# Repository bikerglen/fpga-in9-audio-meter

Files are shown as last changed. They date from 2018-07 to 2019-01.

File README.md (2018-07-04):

# fpga-in9-audio-meter
<p>Clone repo to convenient location</p>
<p>Launch Vivado 2018.2</p>
<p>In TCL console:</p>
<p>cd [path to create project]</p>
<p>source [path to repo]/vivado/create-project.tcl</p>
<p>generate bitstream</p>
<p>export hardware / local / do not include bitstream</p>
<p>launch sdk</p>
<p>create new xilinx standalone hello world application</p>
<p>replace helloworld C code with contents of sdk-c/helloworld.c</p>
<p>add 'm' to helloworld -> properties -> C/C++ Build -> Settings -> Libraries
</p>
<p>to do: rewrite cordic using generate loops</p>

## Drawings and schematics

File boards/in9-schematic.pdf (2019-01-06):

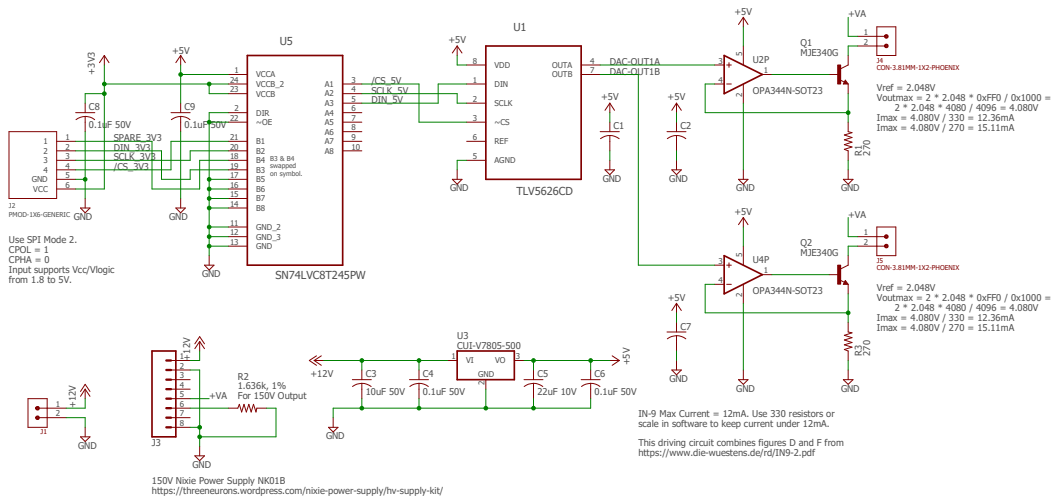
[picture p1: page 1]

2 | DIN_3V3
3 | SCLK_3V3

4 GND 5 VCC 6

Use SPI Mode 2.
CPOL = 1
CPHA = 0
Input supports Vcc/Vlogic
from 1.8 to 5V.

IN-9 Max Current = 12mA. Use 330 resistors or
scale in software to keep current under 12mA.
This driving circuit combines figures D and F from
https://www.die-wuestens.de/rd/IN9-2.pdf

150V Nixie Power Supply NK01B
https://threeneurons.wordpress.com/nixie-power-supply/hv-supply-kit/

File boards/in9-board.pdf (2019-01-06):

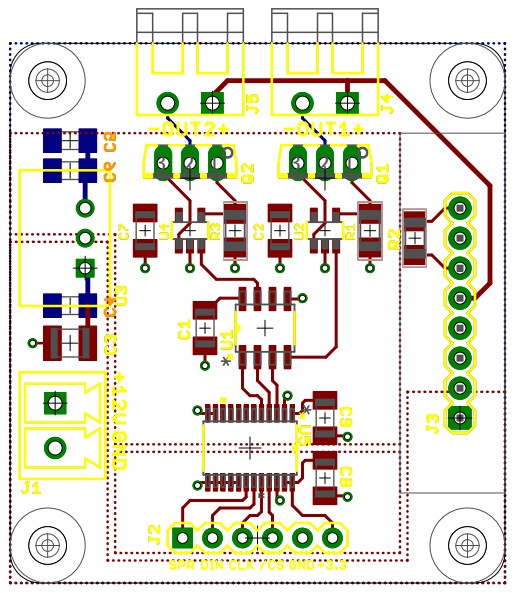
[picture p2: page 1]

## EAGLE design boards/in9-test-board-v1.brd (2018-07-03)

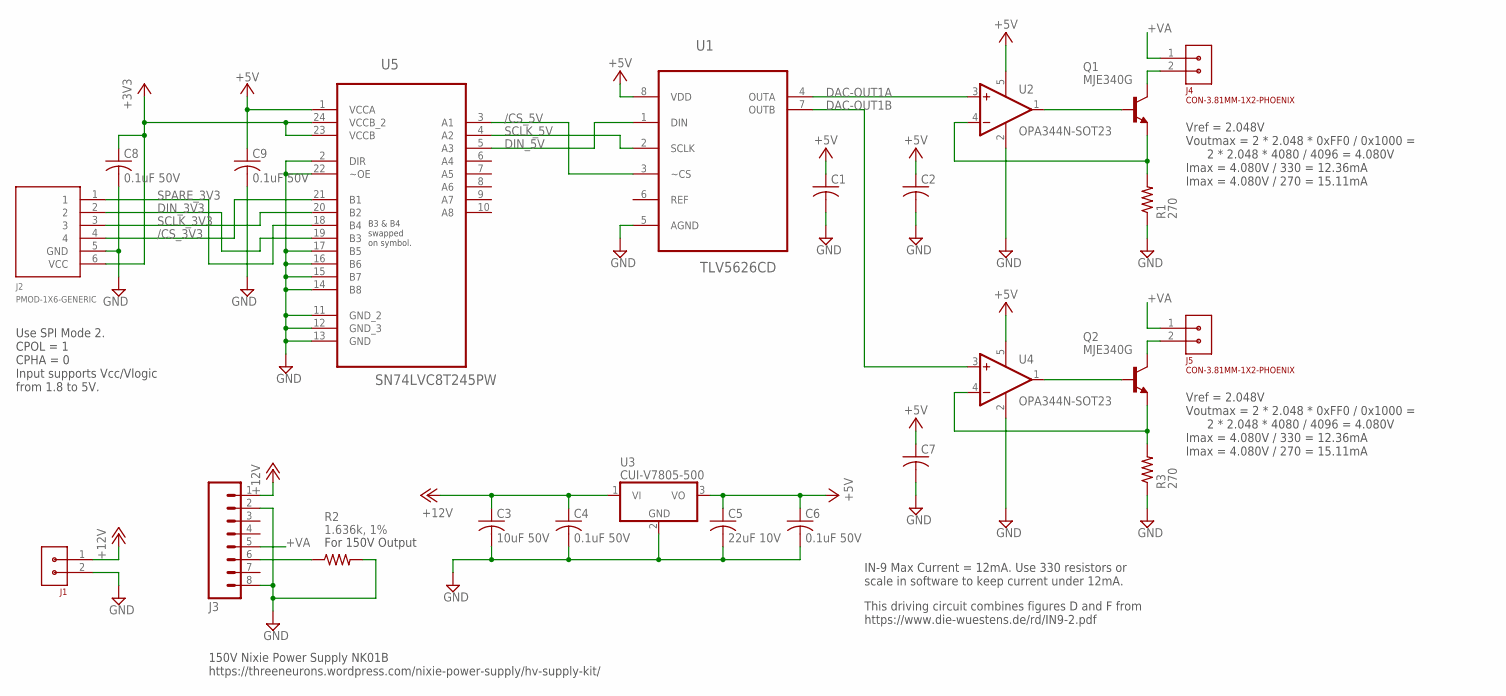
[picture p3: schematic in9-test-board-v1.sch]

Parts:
C1, C2, C7: C-USC1206K; C1206K
C3: 10uF 50V; C1210K; MFR_PART_NO C1210C106K5RACTU
C4, C6, C8, C9: 0.1uF 50V; C1206K; MFR_PART_NO C1206S104M5RACTU
C5: 22uF 10V; C1206K; MFR_PART_NO C1206C226K8RAC7800
J1: CON-3.81MM-1X2-PHOENIX-1803426; CON-PHOENIX-1803426-3.81-1X2
J2: PMOD-1X6-GENERIC; CON-PMOD-1X6
J3: M08; 1X08
J4, J5: CON-3.81MM-1X2-PHOENIX; CON-PHOENIX-3.81-1X2-RA
Q1, Q2: MJE340G; TO126V
R1, R3: 270; R1206
R2: 1.636k, 1%; R1206
U1: TLV5626CD; SOIC127P600X175-8N
U2, U4: OPA344N-SOT23; SOT23-5
U3: CUI-V7805-500; CUI-78XX-500
U5: SN74LVC8T245PW; SOP65P640X120-24N

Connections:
+3V3: C8.1, J2.6 (VCC), U5.23 (VCCB), U5.24 (VCCB_2)
+5V: C1.1, C2.1, C5.1, C6.1, C7.1, C9.1, U1.8 (VDD), U2.5 (V+), U3.3 (VO), U4.5 (V+), U5.1 (VCCA)
+12V: C3.1, C4.1, J1.1, J3.1, U3.1 (VI)
+VA: J3.5, J4.1, J5.1
/CS_3V3: J2.4, U5.21 (B1)
/CS_5V: U1.3 (~CS), U5.3 (A1)
DAC-OUT1A: U1.4 (OUTA), U2.3 (+IN)
DAC-OUT1B: U1.7 (OUTB), U4.3 (+IN)
DIN_3V3: J2.2, U5.19 (B3)
DIN_5V: U1.1 (DIN), U5.5 (A3)
GND: C1.2, C2.2, C3.2, C4.2, C5.2, C6.2, C7.2, C8.2, C9.2, J1.2, J2.5 (GND), J3.2, J3.8, R1.1, R2.2, R3.1, U1.5 (AGND), U2.2 (V-), U3.2 (GND), U4.2 (V-), U5.2 (DIR), U5.11 (GND_2), U5.12 (GND_3), U5.13 (GND), U5.14 (B8), U5.15 (B7), U5.16 (B6), U5.17 (B5), U5.22 (~OE)
unnamed: Q1.1 (E), R1.2, U2.4 (-IN)
unnamed: Q1.3 (B), U2.1 (OUT)
unnamed: J3.6, R2.1
unnamed: Q2.1 (E), R3.2, U4.4 (-IN)
unnamed: Q2.3 (B), U4.1 (OUT)
OUT1A: J4.2, Q1.2 (C)
OUT1B: J5.2, Q2.2 (C)
SCLK_3V3: J2.3, U5.20 (B2)
SCLK_5V: U1.2 (SCLK), U5.4 (A2)
SPARE_3V3: J2.1, U5.18 (B4)

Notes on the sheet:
Vref = 2.048V Voutmax = 2 * 2.048 * 0xFF0 / 0x1000 = 2 * 2.048 * 4080 / 4096 = 4.080V Imax = 4.080V / 330 = 12.36mA Imax = 4.080V / 270 = 15.11mA
For 150V Output
150V Nixie Power Supply NK01B https://threeneurons.wordpress.com/nixie-power-supply/hv-supply-kit/
This driving circuit combines figures D and F from https://www.die-wuestens.de/rd/IN9-2.pdf
B3 & B4 swapped on symbol.
Use SPI Mode 2. CPOL = 1 CPHA = 0 Input supports Vcc/Vlogic from 1.8 to 5V.
IN-9 Max Current = 12mA. Use 330 resistors or scale in software to keep current under 12mA.

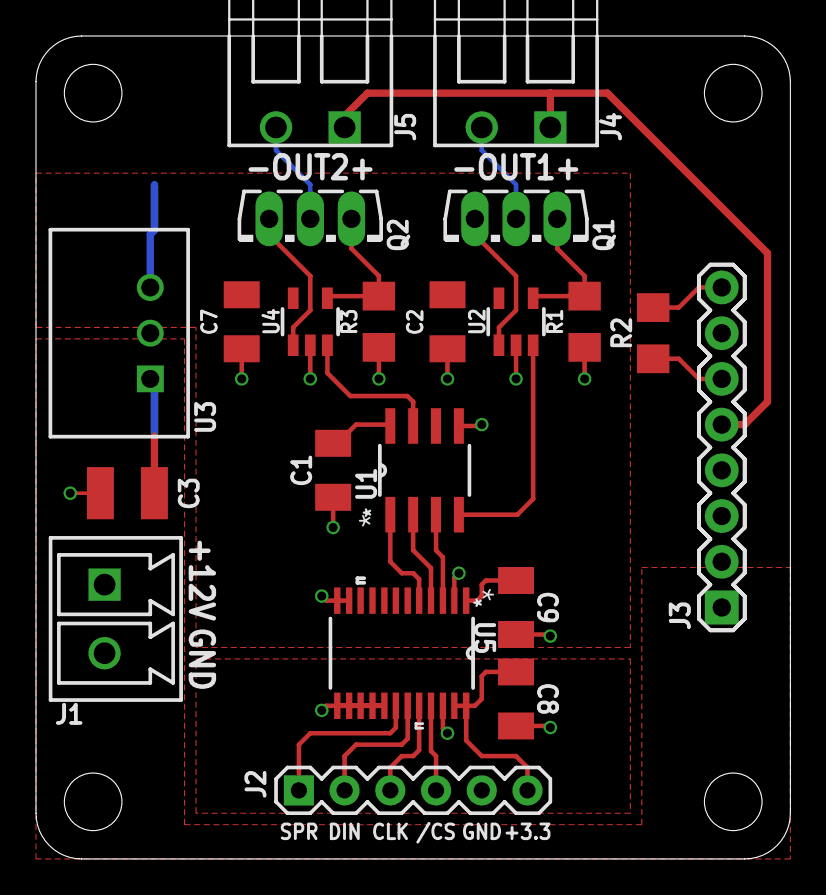
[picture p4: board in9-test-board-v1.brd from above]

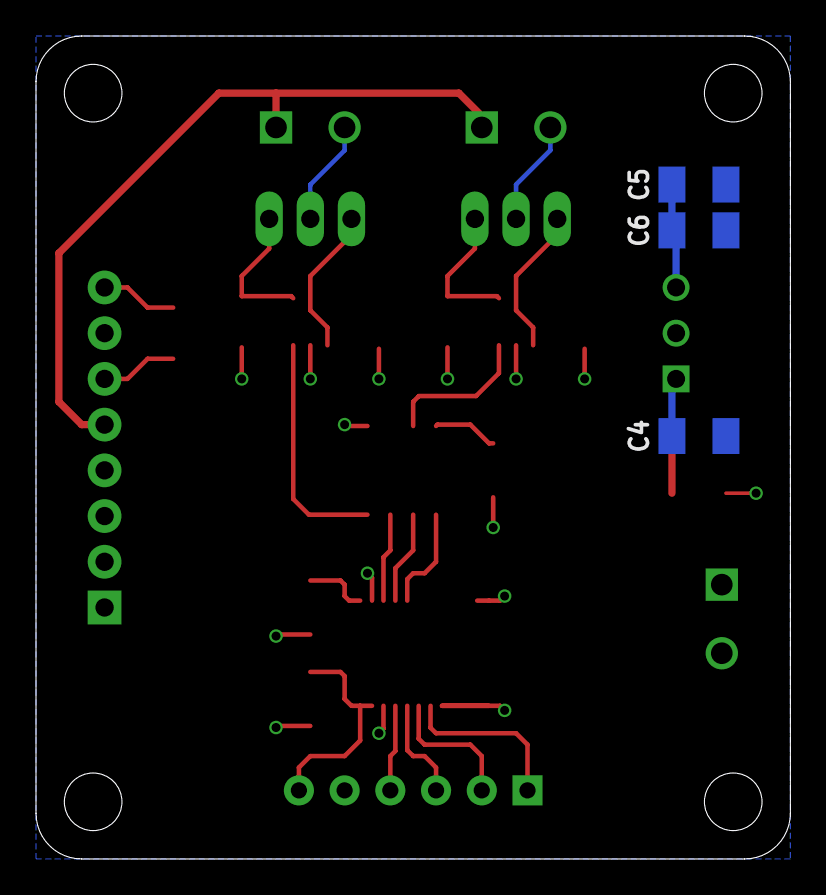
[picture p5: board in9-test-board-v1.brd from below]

Board: 2 copper layers, 41.9 x 45.7 mm, 24 parts (3 on the bottom side), 21 nets.

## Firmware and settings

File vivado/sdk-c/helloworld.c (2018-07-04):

#include <stdio.h>
#include <stdlib.h>
#include <stdint.h>
#include <unistd.h>
#include "platform.h"
#include "xil_printf.h"
#include "xparameters.h"
#include "xil_io.h"
#include <math.h>

#define AUDIO_TEST_0_REG 			(XPAR_AUDIO_WRAPPER_0_BASEADDR + 0x00)
#define AUDIO_TEST_1_REG 			(XPAR_AUDIO_WRAPPER_0_BASEADDR + 0x04)
#define AUDIO_TEST_2_REG 			(XPAR_AUDIO_WRAPPER_0_BASEADDR + 0x08)
#define AUDIO_TEST_3_REG 			(XPAR_AUDIO_WRAPPER_0_BASEADDR + 0x0C)
#define AUDIO_TIMEBASE_VALUE_REG 	(XPAR_AUDIO_WRAPPER_0_BASEADDR + 0x10)
#define AUDIO_TIMEBASE_FLAG_REG 	(XPAR_AUDIO_WRAPPER_0_BASEADDR + 0x14)
#define AUDIO_PEAK_BLOCK_SIZE_REG 	(XPAR_AUDIO_WRAPPER_0_BASEADDR + 0x18)
#define AUDIO_PEAK_FIFO_EMPTY_REG	(XPAR_AUDIO_WRAPPER_0_BASEADDR + 0x1C)
#define AUDIO_PEAK_FIFO_DATA_REG	(XPAR_AUDIO_WRAPPER_0_BASEADDR + 0x20)

#define BARGRAPH_ADDR_REG (XPAR_RGB_LED_BARGRAPH_0_BASEADDR + 0x00)
#define BARGRAPH_DATA_REG (XPAR_RGB_LED_BARGRAPH_0_BASEADDR + 0x04)
#define BARGRAPH_BUFFER_REG (XPAR_RGB_LED_BARGRAPH_0_BASEADDR + 0x08)
#define BARGRAPH_BRIGHTNESS_REG (XPAR_RGB_LED_BARGRAPH_0_BASEADDR + 0x0C)
#define BARGRAPH_TIMER_REG (XPAR_RGB_LED_BARGRAPH_0_BASEADDR + 0x10)
#define BARGRAPH_TIMER_FLAG_REG (XPAR_RGB_LED_BARGRAPH_0_BASEADDR + 0x14)

void SetLevels (void);
void SetDot (uint16_t base, uint8_t n, uint8_t r, uint8_t g, uint8_t b);

const uint8_t gamma8[] = {
    0,  0,  0,  0,  0,  0,  0,  0,  0,  0,  0,  0,  0,  0,  0,  0,
    0,  0,  0,  0,  0,  0,  0,  0,  0,  0,  0,  0,  1,  1,  1,  1,
    1,  1,  1,  1,  1,  1,  1,  1,  1,  2,  2,  2,  2,  2,  2,  2,
    2,  3,  3,  3,  3,  3,  3,  3,  4,  4,  4,  4,  4,  5,  5,  5,
    5,  6,  6,  6,  6,  7,  7,  7,  7,  8,  8,  8,  9,  9,  9, 10,
   10, 10, 11, 11, 11, 12, 12, 13, 13, 13, 14, 14, 15, 15, 16, 16,
   17, 17, 18, 18, 19, 19, 20, 20, 21, 21, 22, 22, 23, 24, 24, 25,
   25, 26, 27, 27, 28, 29, 29, 30, 31, 32, 32, 33, 34, 35, 35, 36,
   37, 38, 39, 39, 40, 41, 42, 43, 44, 45, 46, 47, 48, 49, 50, 50,
   51, 52, 54, 55, 56, 57, 58, 59, 60, 61, 62, 63, 64, 66, 67, 68,
   69, 70, 72, 73, 74, 75, 77, 78, 79, 81, 82, 83, 85, 86, 87, 89,
   90, 92, 93, 95, 96, 98, 99,101,102,104,105,107,109,110,112,114,
  115,117,119,120,122,124,126,127,129,131,133,135,137,138,140,142,
  144,146,148,150,152,154,156,158,160,162,164,167,169,171,173,175,
  177,180,182,184,186,189,191,193,196,198,200,203,205,208,210,213,
  215,218,220,223,225,228,231,233,236,239,241,244,247,249,252,255 };

uint8_t buffer = 0;
uint8_t levels[1][48][3];

#define SCALE  16.0F
#define OFFSET  2.0F
#define DECAY   0.0075F

void LevelsToDots (float *state, int16_t level, uint8_t *nLeds, uint8_t *dac);
void spiSend (int n, unsigned char *d);

int main()
{
	int i;
	uint8_t spiData[2];

    init_platform ();

    print("Hello, world!\n\r");

    printf ("%08lx\n\r", Xil_In32 (AUDIO_TEST_0_REG));
    printf ("%08lx\n\r", Xil_In32 (AUDIO_TEST_1_REG));
    printf ("%08lx\n\r", Xil_In32 (AUDIO_TEST_2_REG));
    printf ("%08lx\n\r", Xil_In32 (AUDIO_TEST_3_REG));

    // configure manual slave select, spi mode 2 (CPOL=1, CPHA=0), master mode, enabled
	Xil_Out32 (XPAR_SPI_0_BASEADDR + 0x60, 0x8E);

	for (i = 0; i < 5; i++) {
		// clear timer flag then wait for timer flag to be set
		Xil_Out32 (BARGRAPH_TIMER_FLAG_REG, 0x1);
		while (Xil_In32 (BARGRAPH_TIMER_FLAG_REG) == 0) {
		}
	}

    // initiailze DAC, slow mode, powered up, use 2.048V internal ref voltage
    spiData[0] = 0x90;
    spiData[1] = 0x02;
    spiSend (2, spiData);

    // write DAC B value to buffer
    spiData[0] = 0x10;
    spiData[1] = 0x00;
    spiSend (2, spiData);

    // write DAC A value and move buffer to DAC B simultaneously
    spiData[0] = 0x80;
    spiData[1] = 0x00;
    spiSend (2, spiData);

    // blank both display buffers
    Xil_Out32 (BARGRAPH_ADDR_REG, 0x00000000);
    for (i = 0; i < 512; i++) {
        Xil_Out32 (BARGRAPH_DATA_REG, 0x00000000);
    }

    // select display buffer 0
    Xil_Out32 (BARGRAPH_BUFFER_REG, 0x0);

    // set global brightness to full
    Xil_Out32 (BARGRAPH_BRIGHTNESS_REG, 0x100);

    // set periodic interval timer to 30Hz
    Xil_Out32 (BARGRAPH_TIMER_REG, 1666666);

    float state_left = 0;
    float state_right = 0;

    while (1) {
		uint8_t leds_left, leds_right, dac_left, dac_right;
		uint8_t spiData[2];

		if (!Xil_In32 (AUDIO_PEAK_FIFO_EMPTY_REG)) {
    		uint32_t d = Xil_In32 (AUDIO_PEAK_FIFO_DATA_REG);
    		int16_t l_int = (d >> 16);
    		int16_t r_int = (d & 0xffff);

    		LevelsToDots (&state_left, l_int, &leds_left, &dac_left);
    		LevelsToDots (&state_right, r_int, &leds_right, &dac_right);

			for (i = 0; i < 48; i++) {
				levels[0][i][0] = (i < leds_left) ? 255 : 0;
			}
			SetLevels ();

		    // write DAC B value to buffer
		    spiData[0] = 0x10 | ((dac_right >> 4) & 0x0f);
		    spiData[1] = 0x00 | ((dac_right << 4) & 0xf0);
		    spiSend (2, spiData);

		    // write DAC A value and move buffer to DAC B simultaneously
		    spiData[0] = 0x80 | ((dac_left >> 4) & 0x0f);
		    spiData[1] = 0x00 | ((dac_left << 4) & 0xf0);
		    spiSend (2, spiData);

		    xil_printf (".");
			// printf ("%2d %3d\n\r", leds_left, dac_left);
    	}
    }


    cleanup_platform();

    return 0;
}


void LevelsToDots (float *state, int16_t level, uint8_t *nLeds, uint8_t *dac)
{
	float dB = (float)level / 128.0;

	float percent = (dB + OFFSET + SCALE) / SCALE;			// each segment represents 1.5dB
	if (percent > 1.0) percent = 1.0;
	else if (percent < 0.0) percent = 0.0;

	float decayed = *state - DECAY;
	if (decayed < 0) decayed = 0;
	*state = (percent > decayed) ? percent : decayed;
	*nLeds = ceil (*state * 48);
	*dac = ceil (*state * 255);
}


void SetLevels (void)
{
	int n;
	uint16_t base;

	if (buffer == 0) {
		base = 0x000;
	} else {
		base = 0x100;
	}

	for (n = 0; n < 48; n++) {
		SetDot (base, n, levels[0][n][0], levels[0][n][1], levels[0][n][2]);
	}

	if (buffer == 0) {
		Xil_Out32 (BARGRAPH_BUFFER_REG, 0x0);
		buffer = 1;
	} else {
		Xil_Out32 (BARGRAPH_BUFFER_REG, 0x1);
		buffer = 0;
	}
}


void SetDot (uint16_t base, uint8_t n, uint8_t r, uint8_t g, uint8_t b)
{
	uint8_t row = 16*(n/3);
	uint8_t col = 13 - 3*(n%3);
	uint16_t address = base + row + col;

    Xil_Out32 (BARGRAPH_ADDR_REG, address);
	Xil_Out32 (BARGRAPH_DATA_REG, gamma8[b]);
	Xil_Out32 (BARGRAPH_DATA_REG, gamma8[g]);
	Xil_Out32 (BARGRAPH_DATA_REG, gamma8[r]);
}


void spiSend (int n, uint8_t *data)
{
	uint16_t chip_selects;

	chip_selects = 0xFFFF & ~1;
	Xil_Out32 (XPAR_SPI_0_BASEADDR + 0x70, chip_selects);

	while (n--) {
		Xil_Out32 (XPAR_SPI_0_BASEADDR + 0x68, *data++);
		while (Xil_In32 (XPAR_SPI_0_BASEADDR + 0x64) & 0x8) {
		}
	}

	Xil_Out32 (XPAR_SPI_0_BASEADDR + 0x70, 0xFFFF);
}

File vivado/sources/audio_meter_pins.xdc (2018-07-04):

set_clock_groups -asynchronous -group { clk_fpga_0 } -group { clk_out1_system_clk_wiz_0_0 }

## Pmod Header JA
set_property -dict { PACKAGE_PIN Y18 IOSTANDARD LVCMOS33 } [get_ports { tx_mclk  }]; #JA[0] IO_L17P_T2_34 Sch=ja_p[1]
set_property -dict { PACKAGE_PIN Y19 IOSTANDARD LVCMOS33 } [get_ports { tx_lrck  }]; #JA[1] IO_L17N_T2_34 Sch=ja_n[1]
set_property -dict { PACKAGE_PIN Y16 IOSTANDARD LVCMOS33 } [get_ports { tx_sclk  }]; #JA[2] IO_L7P_T1_34 Sch=ja_p[2]
set_property -dict { PACKAGE_PIN Y17 IOSTANDARD LVCMOS33 } [get_ports { tx_sdout }]; #JA[3] IO_L7N_T1_34 Sch=ja_n[2]
set_property -dict { PACKAGE_PIN U18 IOSTANDARD LVCMOS33 } [get_ports { rx_mclk  }]; #JA[4] IO_L12P_T1_MRCC_34 Sch=ja_p[3]
set_property -dict { PACKAGE_PIN U19 IOSTANDARD LVCMOS33 } [get_ports { rx_lrck  }]; #JA[5] IO_L12N_T1_MRCC_34 Sch=ja_n[3]
set_property -dict { PACKAGE_PIN W18 IOSTANDARD LVCMOS33 } [get_ports { rx_sclk  }]; #JA[6] IO_L22P_T3_34 Sch=ja_p[4]
set_property -dict { PACKAGE_PIN W19 IOSTANDARD LVCMOS33 } [get_ports { rx_sdin  }]; #JA[7] IO_L22N_T3_34 Sch=ja_n[4]

## Pmod Header JB
set_property -dict { PACKAGE_PIN W14 IOSTANDARD LVCMOS33 } [get_ports { spi_spare }]; # JB[0] IO_L8P_T1_34 Sch=jb_p[1]
set_property -dict { PACKAGE_PIN Y14 IOSTANDARD LVCMOS33 } [get_ports { spi_mosi  }]; # JB[1] IO_L8N_T1_34 Sch=jb_n[1]
set_property -dict { PACKAGE_PIN T11 IOSTANDARD LVCMOS33 } [get_ports { spi_sclk  }]; # JB[2] IO_L1P_T0_34 Sch=jb_p[2]
set_property -dict { PACKAGE_PIN T10 IOSTANDARD LVCMOS33 } [get_ports { spi_ss0   }]; # JB[3] IO_L1N_T0_34 Sch=jb_n[2]

#set_property -dict { PACKAGE_PIN W14 IOSTANDARD LVCMOS33 } [get_ports { row[1]   }]; # JB[0] IO_L8P_T1_34 Sch=jb_p[1]
#set_property -dict { PACKAGE_PIN Y14 IOSTANDARD LVCMOS33 } [get_ports { row[3]   }]; # JB[1] IO_L8N_T1_34 Sch=jb_n[1]
#set_property -dict { PACKAGE_PIN T11 IOSTANDARD LVCMOS33 } [get_ports { col      }]; # JB[2] IO_L1P_T0_34 Sch=jb_p[2]
#set_property -dict { PACKAGE_PIN T10 IOSTANDARD LVCMOS33 } [get_ports { latch    }]; # JB[3] IO_L1N_T0_34 Sch=jb_n[2]
#set_property -dict { PACKAGE_PIN V16 IOSTANDARD LVCMOS33 } [get_ports { row[0]   }]; # JB[4] IO_L18P_T2_34 Sch=jb_p[3]
#set_property -dict { PACKAGE_PIN W16 IOSTANDARD LVCMOS33 } [get_ports { row[2]   }]; # JB[5] IO_L18N_T2_34 Sch=jb_n[3]
#set_property -dict { PACKAGE_PIN V12 IOSTANDARD LVCMOS33 } [get_ports { blank    }]; # JB[6] IO_L4P_T0_34 Sch=jb_p[4]
#set_property -dict { PACKAGE_PIN W13 IOSTANDARD LVCMOS33 } [get_ports { sclk     }]; # JB[7] IO_L4N_T0_34 Sch=jb_n[4]

set_property -dict { PACKAGE_PIN U14   IOSTANDARD LVCMOS33 } [get_ports { row[1] }]; #IO_L11P_T1_SRCC_34 Sch=ck_io[0]
set_property -dict { PACKAGE_PIN V13   IOSTANDARD LVCMOS33 } [get_ports { row[3] }]; #IO_L3N_T0_DQS_34 Sch=ck_io[1]
set_property -dict { PACKAGE_PIN T14   IOSTANDARD LVCMOS33 } [get_ports { col }]; #IO_L5P_T0_34 Sch=ck_io[2]
set_property -dict { PACKAGE_PIN T15   IOSTANDARD LVCMOS33 } [get_ports { latch }]; #IO_L5N_T0_34 Sch=ck_io[3]
set_property -dict { PACKAGE_PIN V17   IOSTANDARD LVCMOS33 } [get_ports { row[0] }]; #IO_L21P_T3_DQS_34 Sch=ck_io[4]
set_property -dict { PACKAGE_PIN V18   IOSTANDARD LVCMOS33 } [get_ports { row[2] }]; #IO_L21N_T3_DQS_34 Sch=ck_io[5]
set_property -dict { PACKAGE_PIN R17   IOSTANDARD LVCMOS33 } [get_ports { blank }]; #IO_L19N_T3_VREF_34 Sch=ck_io[6]
set_property -dict { PACKAGE_PIN R14   IOSTANDARD LVCMOS33 } [get_ports { sclk }]; #IO_L6N_T0_VREF_34 Sch=ck_io[7]
#set_property -dict { PACKAGE_PIN N18   IOSTANDARD LVCMOS33 } [get_ports { ck_io8 }]; #IO_L13P_T2_MRCC_34 Sch=ck_io[8]
#set_property -dict { PACKAGE_PIN M18   IOSTANDARD LVCMOS33 } [get_ports { ck_io9 }]; #IO_L8N_T1_AD10N_35 Sch=ck_io[9]
#set_property -dict { PACKAGE_PIN U15   IOSTANDARD LVCMOS33 } [get_ports { ck_io10 }]; #IO_L11N_T1_SRCC_34 Sch=ck_io[10]
#set_property -dict { PACKAGE_PIN K18   IOSTANDARD LVCMOS33 } [get_ports { ck_io11 }]; #IO_L12N_T1_MRCC_35 Sch=ck_io[11]
#set_property -dict { PACKAGE_PIN J18   IOSTANDARD LVCMOS33 } [get_ports { ck_io12 }]; #IO_L14P_T2_AD4P_SRCC_35 Sch=ck_io[12]
#set_property -dict { PACKAGE_PIN G15 IOSTANDARD LVCMOS33 } [get_ports { ck_io13 }]; #IO_L19N_T3_VREF_35 Sch=ck_io[13]

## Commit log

2018-07-03 initial checkin
    [in9-test-board-v1.brd, in9-test-board-v1.sch]
2018-07-04 added -lm switch to sdk build
2019-01-06 added PDFs of schematic and board
2019-01-06 fixed landscape print
